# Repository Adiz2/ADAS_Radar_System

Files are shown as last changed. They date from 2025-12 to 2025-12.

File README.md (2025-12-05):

# ADAS Radar Controller Board with Hardware and Software Co-design
# Project Overview 
  This project implements a complete embedded system for an ADAS Radar Controller with Frequency Modulated Continuous Wave (FMCW) as an input signal. This project demonstartes a full-cycle engineering workflow,     bridging the gap between DSP algorithms, RTL Design, Physical Design (Timing Closure) and Board Layout. This system generates a precise frequecy sweep (Chirp) used in automotive ADAS systems for distance and
  velocity measurement integrated on a Xilinx Zynq-7000 SoC.
# Key Technical Achievements
  1. Register Transfer Level (RTL) Design and Digital Signal Processing (DSP):-
     Designed a custom Numerically Controlled Oscillator (NCO) core in Verilog to generate precise linear frequency chirps. Implemented a synchronous Phase Accumulator and Look-Up Table (LUT) architecture for
     digital architecture for digital waveform synthesis.
     Source Code: lut.v
  2. Verification (SystemVerilog):-
     Developed a self-checking SystemVerilog testbench to verify the phase accumulation logic before synthesis. Validated the digital output by comparing the quantised phase steps against an ideal mathematical
     model.
     Source Code: radar_chirp_tb.sv
  3. Physical Design and Timing Closure:-
     Performed Static Timing Analysis (STA) on a high-speed 1GHz clock domain to simulate high-performance requirements.
     Challenge: Encountered a critical timing violation Worst Negative Slack (WNS) = -0.669ns.
     Solution: Developed a Tcl Floorplanning script to manually constrain logic cell placement (Pblocks), reducing routing delay.
     Result: Successfully closed timing with a final WNS of 2.527ns, Worst Hold Slack (WHS) as 0.118ns and Worst Pulse Width Slack (WPWS) as 3.000ns.
     Script: floorplan_fix.tcl
  4. Hardware Design:
     Designed a custom 4-layer carrier board in Altium Designer for the XC7Z020 FPGA.
     Features:
       Routed high-speed DDR3 memory interface with length matching.
       Designed a complete power regulation network (1.0V, 1.5V, 1.8V, 3.3V) from a 5V USB source.
       Implemented JTAG Configuration and System Clock Infrastructure.
     Schematic: FPGA_Top.pdf
  5. Embedded Software
     Integrated the custom hardware into a MicroBlaze embedded processor system via the AXI4-Lite bus. Dveloped bare-metal C drivers to write frequency control words and read back status registers via memory
     mapped-I/O.
     Source Code: main.c
# Real World Applications:
  This technology is the fundamental building block for:
  1. Automotive ADAS: Adaptive Cruise Control and Collision Avoidance
  2. Altimeters: Precision height measurement for drones,aircrafts etc.
  3. Weather Radar: Doppler frequency shift analysis.
# Tools Used
  FPGA: Xilinx Vivado, Vitis IDE, SystemVerilog, Tcl Scripting
  Hardware: Altium Designer - PCB & Schematic
  Simulation: MATLAB Simulink, Vitis Model Composer
# Designed and Verified by B.S. Aditya Meher

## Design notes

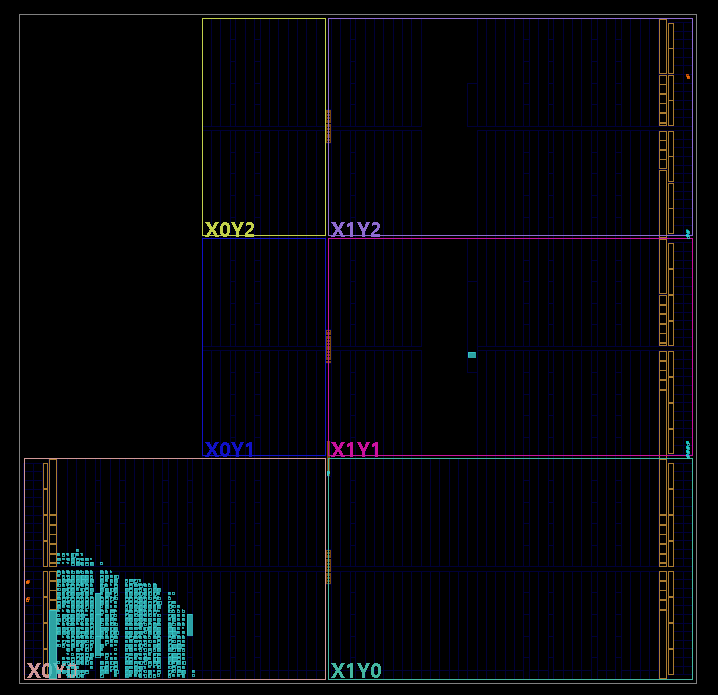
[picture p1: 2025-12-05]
Implemented Design.png

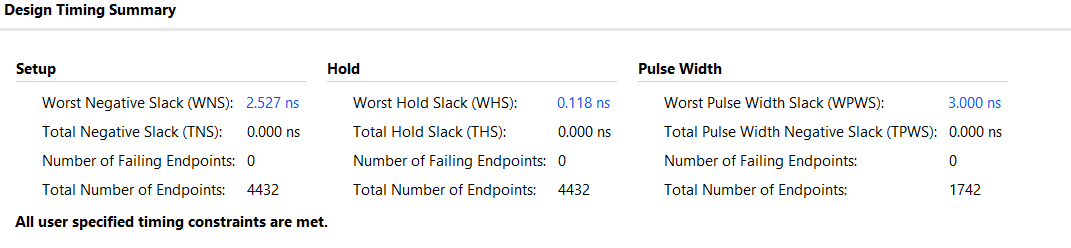
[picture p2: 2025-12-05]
Design Timing Summary Report.png

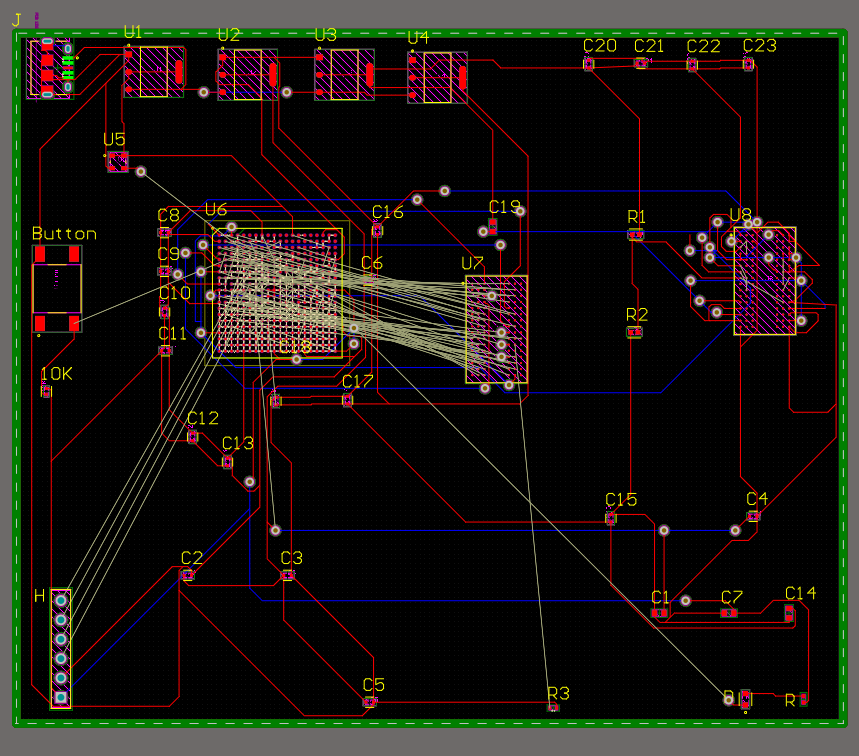
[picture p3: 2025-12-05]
PCB-2D.png

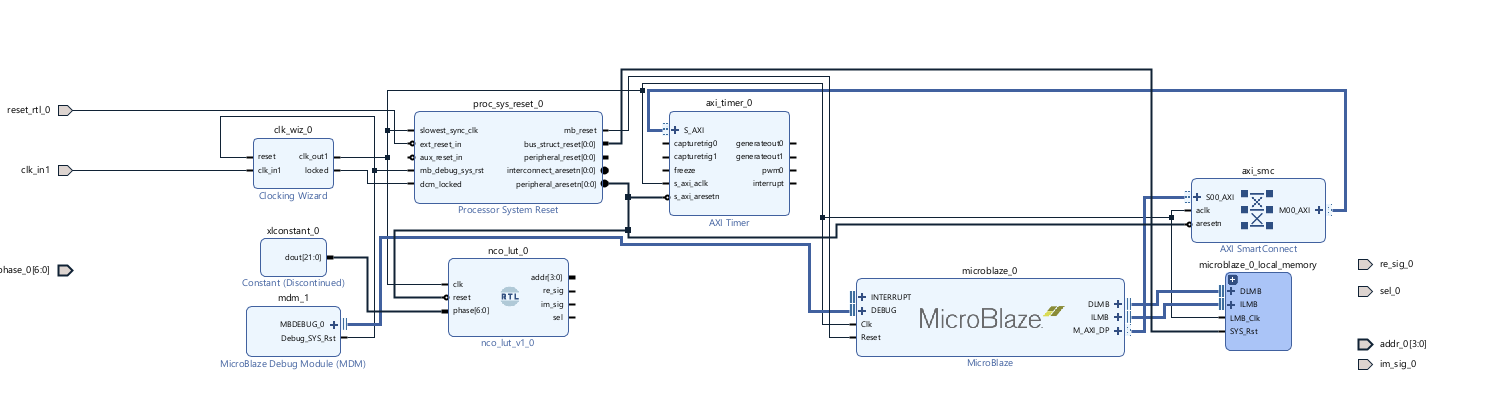
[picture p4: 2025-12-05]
Block Diagram.png

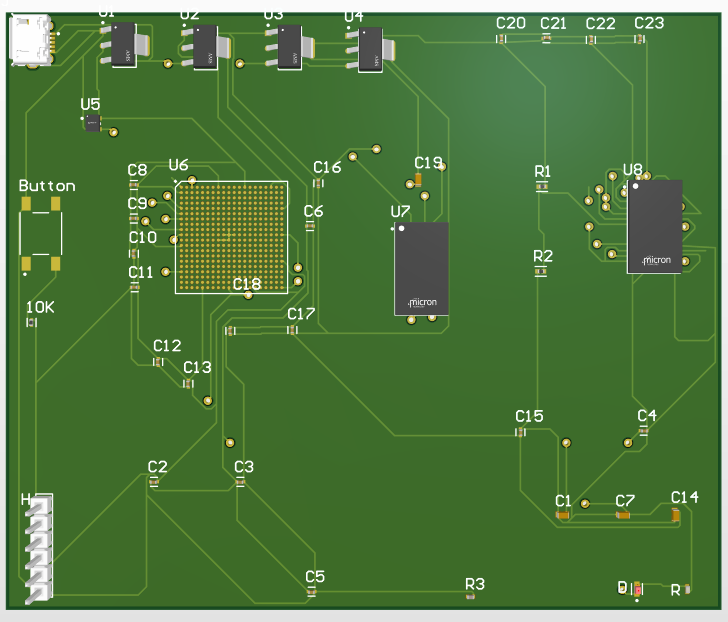
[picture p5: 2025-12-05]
ADAS_Radar_Controller.png

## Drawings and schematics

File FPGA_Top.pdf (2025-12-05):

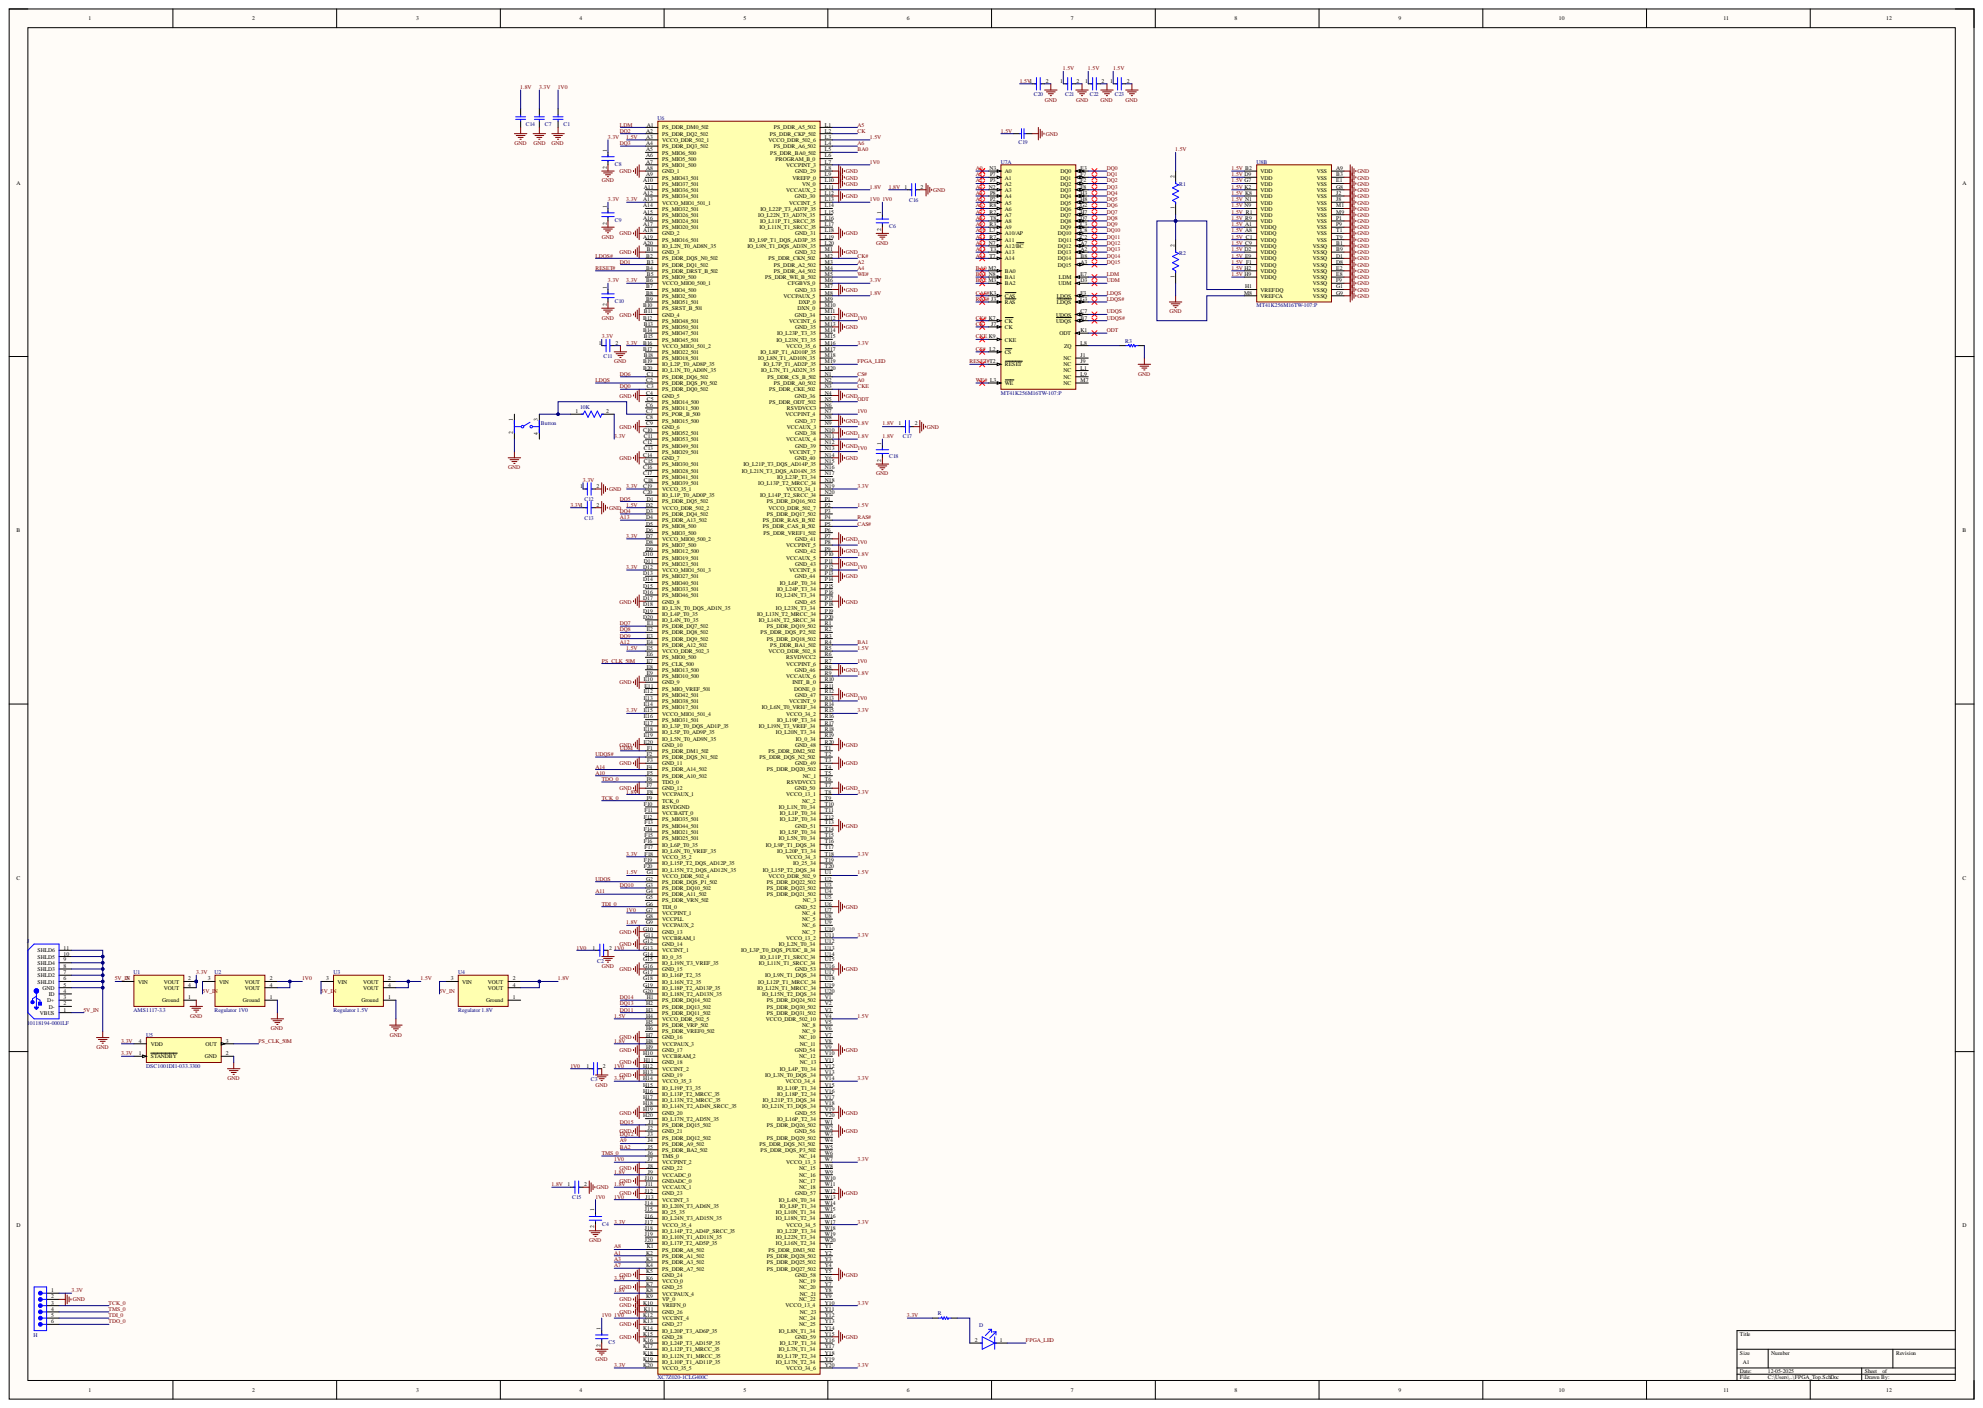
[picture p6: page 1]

1 2 10K | PS_MIO11_500 C6 PS_POR_B_500 C7

PS_MIO15_500 C8

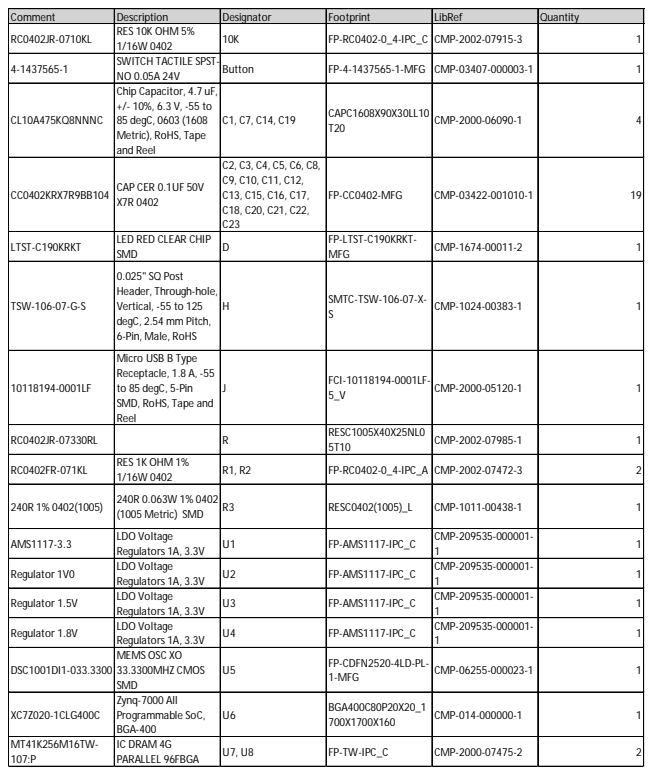
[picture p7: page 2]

Comment | Description | Designator | Footprint | LibRef | Quantity
RC0402JR-0710KL | RES 10K OHM 5% 1/16W 0402 | 10K | FP-RC0402-0_4-IPC_C | CMP-2002-07915-3 | 1

4-1437565-1 | SWITCH TACTILE SPST-NO 0.05A 24V | Button | FP-4-1437565-1-MFG | CMP-03407-000003-1 | 1

CL10A475KQ8NNNC | Chip Capacitor, 4.7 uF, +/- 10%, 6.3 V, -55 to 85 degC, 0603 (1608 Metric), RoHS, Tape and Reel | C1, C7, C14, C19 | CAPC1608X90X30LL10 T20 | CMP-2000-06090-1 | 4

CC0402KRX7R9BB104 | CAP CER 0.1UF 50V X7R 0402 | C2, C3, C4, C5, C6, C8, C9, C10, C11, C12, C13, C15, C16, C17, C18, C20, C21, C22, C23 | FP-CC0402-MFG | CMP-03422-001010-1 | 19

LTST-C190KRKT | LED RED CLEAR CHIP SMD | D | FP-LTST-C190KRKT-MFG | CMP-1674-00011-2 | 1

TSW-106-07-G-S | 0.025" SQ Post Header, Through-hole, Vertical, -55 to 125 degC, 2.54 mm Pitch, 6-Pin, Male, RoHS | H | SMTC-TSW-106-07-X-S | CMP-1024-00383-1 | 1

10118194-0001LF | Micro USB B Type Receptacle, 1.8 A, -55 to 85 degC, 5-Pin SMD, RoHS, Tape and Reel | J | FCI-10118194-0001LF-5_V | CMP-2000-05120-1 | 1

RC0402JR-07330RL | | R | RESC1005X40X25NL0 5T10 | CMP-2002-07985-1 | 1

RC0402FR-071KL | RES 1K OHM 1% 1/16W 0402 | R1, R2 | FP-RC0402-0_4-IPC_A | CMP-2002-07472-3 | 2

240R 1% 0402(1005) | 240R 0.063W 1% 0402 (1005 Metric) SMD | R3 | RESC0402(1005)_L | CMP-1011-00438-1 | 1

AMS1117-3.3 | LDO Voltage Regulators 1A, 3.3V | U1 | FP-AMS1117-IPC_C | CMP-209535-000001-1 | 1

Regulator 1V0 | LDO Voltage Regulators 1A, 3.3V | U2 | FP-AMS1117-IPC_C | CMP-209535-000001-1 | 1

Regulator 1.5V | LDO Voltage Regulators 1A, 3.3V | U3 | FP-AMS1117-IPC_C | CMP-209535-000001-1 | 1

Regulator 1.8V | LDO Voltage Regulators 1A, 3.3V | U4 | FP-AMS1117-IPC_C | CMP-209535-000001-1 | 1

DSC1001DI1-033.3300 | MEMS OSC XO 33.3300MHZ CMOS SMD | U5 | FP-CDFN2520-4LD-PL-1-MFG | CMP-06255-000023-1 | 1

XC7Z020-1CLG400C | Zynq-7000 All Programmable SoC, BGA-400 | U6 | BGA400C80P20X20_1 700X1700X160 | CMP-014-000000-1 | 1

MT41K256M16TW-107:P | IC DRAM 4G PARALLEL 96FBGA | U7, U8 | FP-TW-IPC_C | CMP-2000-07475-2 | 2

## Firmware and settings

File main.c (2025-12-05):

#include <stdio.h>
#include "platform.h"
#include "xil_printf.h"
#include "xil_io.h"        // Required for Xilinx register Read/Write
#include "xparameters.h"   // Contains hardware base addresses

// --- Define the Base Address for your Custom IP ---
// This address must match what is in your Vivado Address Editor.
// If you are unsure, 0x44A00000 is the standard default for the first AXI peripheral.
#define NCO_LUT_BASE_ADDR 0x44A00000 

int main()
{
    init_platform();

    print("\n\r--- ADAS RADAR CHIRP CONTROLLER STARTING ---\n\r");

    u32 status_val;
    u32 start_command = 0x00000001; // Bit 0 = Start

    // 1. Control Demonstration: Write a 'Start' Command
    // We write the value '1' to the register at Offset 0
    Xil_Out32(NCO_LUT_BASE_ADDR + 0x0, start_command); 
    xil_printf("WROTE Start Command (0x%08x) to Address 0x%08x\n\r", start_command, NCO_LUT_BASE_ADDR);

    // 2. Readback Demonstration: Check Status
    // We read the value from the register at Offset 4 (assuming status is mapped there)
    status_val = Xil_In32(NCO_LUT_BASE_ADDR + 0x4); 
    xil_printf("READ Status Register (Offset 4): 0x%08x\n\r", status_val);

    print("--- SYSTEM CHECK COMPLETE ---\n\r");

    cleanup_platform();
    return 0;
}

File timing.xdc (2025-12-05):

# --- FINAL I/O CONSTRAINTS (CORRECTED VOLTAGES) ---

# 1. System Inputs (Clock & Reset) - MUST be LVCMOS33 (3.3V)
# These are in Bank 13, which is powered by 3.3V on your board.
set_property PACKAGE_PIN Y9 [get_ports clk_in1]
set_property IOSTANDARD LVCMOS33 [get_ports clk_in1]

set_property PACKAGE_PIN W10 [get_ports reset_rtl_0]
set_property IOSTANDARD LVCMOS33 [get_ports reset_rtl_0]

# 2. NCO Address Bus (Unused outputs - Terminate safely)
set_property PACKAGE_PIN U10 [get_ports {addr[3]}]
set_property PACKAGE_PIN T10 [get_ports {addr[2]}]
set_property PACKAGE_PIN R10 [get_ports {addr[1]}]
set_property PACKAGE_PIN P10 [get_ports {addr[0]}]
set_property IOSTANDARD LVCMOS33 [get_ports {addr[*]}]

# 3. Radar Signal Outputs (PL Pins) - Using 3.3V
# C3 is a PS pin (Forbidden). Using N10/M10/L10 which are valid PL pins.
set_property PACKAGE_PIN M19 [get_ports re_sig_0]
set_property PACKAGE_PIN M10 [get_ports im_sig_0]
set_property PACKAGE_PIN L10 [get_ports sel_0]

set_property IOSTANDARD LVCMOS33 [get_ports {re_sig_0 im_sig_0 sel_0}]
